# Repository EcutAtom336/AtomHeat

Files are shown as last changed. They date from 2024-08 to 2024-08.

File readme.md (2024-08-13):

# MINI 加热台 - AtomHeat

## 项目简介

- 该项目是基于立创·天空星开发板-GD32F407VET6-青春版的小型加热台。

- 支持使用 Type-C 接口和 5.5*2.5 DC 接口供电。Type-C 接口最高支持 100W PD 协议，DC 接口支持 16.5v-25.5v 电压。

## 快速链接

- [Github](https://github.com/EcutAtom336/AtomHeat)

- [立创开源硬件平台](http://oshwhub.com/dter/atomheat)

## 功能描述

- 使用 Type-C 接口或 DC 接口供电。理论工作电压为 16.5v-25.5v，兼容 5-6 串锂电池实际仅测试 100W PD 供电。

- 内置加速度计和蜂鸣器，当机身倾倒时候会停止加热并发出提示音。

- 5 个触摸按键和一个旋钮编码器，可设置分时分段加热。可储存5个快捷温度预设。

- 1.8 寸 tft lcd，可显示加热功率、当前温度和加热曲线。

## 复刻指南

### 硬件

#### 硬件架构

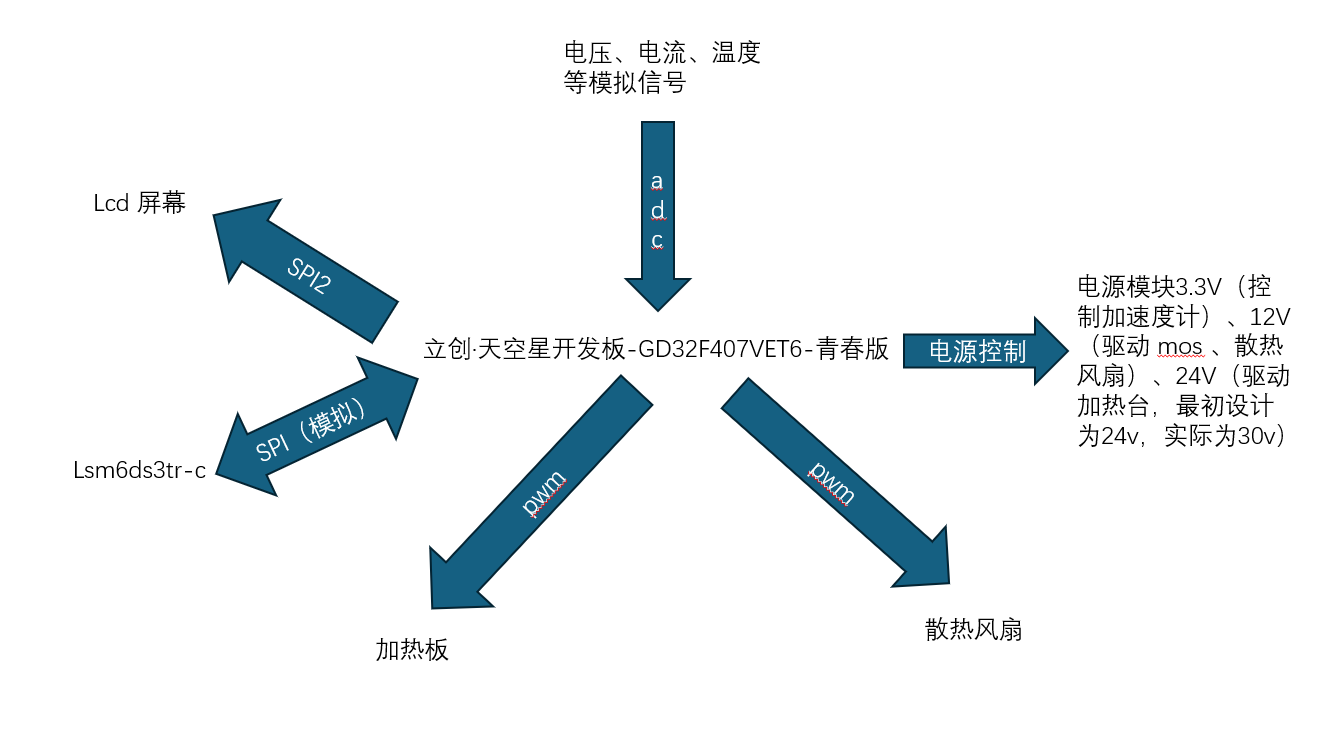
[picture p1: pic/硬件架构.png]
硬件架构


- 项目 BOM 表在 /production_doc 下，分别为：

1. BOM_Board1_V0.3_Schematic1_V0.3_2024-08-13.xlsx

2. BOM_Board2_V0.2_Schematic2_V0.2_2024-08-13.xlsx

- 3D 打印外壳文件在 /production_doc/3d_print 下。

- CNC 制造文件在 /production_doc/cnc 下。

- 面板制造文件在 /production_doc/panel 下。

- PCB 制造文件在 /production_doc/pcb 下。

- 其他硬件在 /production_doc/other.xlsx 有详细介绍和购买地址。

### 软件

#### 软件架构

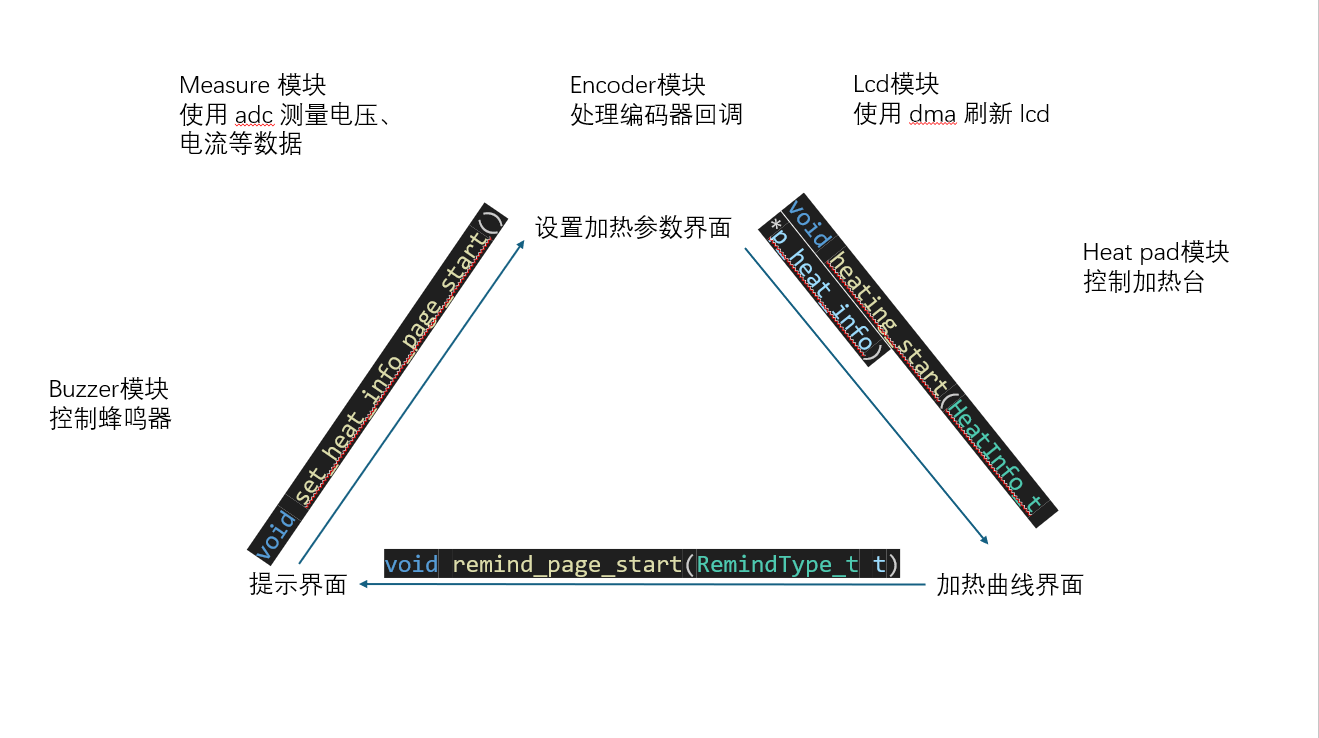
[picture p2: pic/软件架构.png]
软件架构


- 软件使用 EIDE 开发，源码在 /embed 下，该目录 readme 有详细的软件介绍。

### 烧录

- 已编译的固件已上传至附件

- 有多种方式烧录固件，可前往[立创开发板资料](https://lceda001.feishu.cn/wiki/Zawdwg0laig3Qnk2XuxcKrQRn2g)查看详细教程

## 安全警告

- Type-C 接口和 DC 接口没有防倒灌设计，请勿同时使用 Type-C 接口和 DC 接口供电，否则后果自负。

- 加热台工作时，请注意安全。

## 备注

- 加热控制使用 pwm 控制平均功率，瞬时功率大约 120W 以上，即使使用功率限制功能，小功率充电器依然可能过载重启（例如使用 67W 充电器并将最大功率限制在 60W）。

- 当温度达到 300 摄氏度以上时，散热功率接近加热功率，温度上升非常缓慢。

- 为适应项目需求中的低压、高温，本项目使用了 cnc 加工，复刻成本较高。

- 演示视频链接

1.[【星火计划-悬赏赛道】MINI加热台 AtomHeat 功能演示1](https://www.bilibili.com/video/BV15wYYe4EQf/?share_source=copy_web&vd_source=9ee252657cef98d209294340e74664c1)

2.[【星火计划-悬赏赛道】MINI加热台 AtomHeat 功能演示2](https://www.bilibili.com/video/BV1ewYYe4Ey1/?share_source=copy_web&vd_source=9ee252657cef98d209294340e74664c1)

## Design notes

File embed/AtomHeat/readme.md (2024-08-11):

# MINI 加热台 - AtomHeat 软件部分

## 子模块（位于 hal）

- buzzer

对应用提供预设的 buzzer 音频。

向应用层提供以下方法和类型。

```c
typedef enum {
  BuzzerToneSuccess,
  BuzzerToneFail,
  BuzzerToneWarning,
  BuzzerToneClick,
  BuzzerTone4khz500ms,
  BuzzerToneMax
} BuzzerToneNum_t;

/**
 * @brief 蜂鸣器相关初始化
 *
 */
void buzzer_init();

/**
 * @brief 蜂鸣器发声
 *
 * @param tone_num 音频编号
 */
void buzzer_sing(BuzzerToneNum_t tone_num);
```

- encoder

管理编码器相关回调。

向应用层提供以下方法和类型：

```c
typedef void (*EncoderCb_t)(int8_t change_val);

/**
 * @brief 编码器相关初始化
 *
 */
void encoder_init();

/**
 * @brief 添加编码器处理回调（仅支持一个回调）
 *
 * @param cb
 */
void encoder_cb_add(EncoderCb_t cb);

/**
 * @brief 删除编码器处理回调
 *
 */
void encoder_cb_del();
```

- heat_info

加热参数类型和加热参数修正。

向应用层提供以下方法和类型：

```c
typedef struct {
  uint32_t duartion_s;
  uint16_t temp;
} HeatStage_t;

typedef struct {
  uint8_t is_constant : 1;
  uint8_t check_slant : 1;
  uint8_t power_limit;
  HeatStage_t stage[5];
} HeatInfo_t;

/**
 * @brief 检测并修正加热信息参数
 *
 * @param p_heat_info
 */
void heat_info_revise(HeatInfo_t* p_heat_info);
```

- heat_pad

加热板控制相关。

向应用层提供以下方法：

```c
/**
* @brief 加热板相关初始化
*
*/
void heat_pad_init();
/**
 * @brief 失能加热板
 *
 */
void heat_pad_disable();

/**
 * @brief 设置加热台最大功率，该操作会自动使能加热板
 * 
 * @param p 功率
 */
void heat_pad_set_max_pwr(uint8_t p);

/**
 * @brief 设置加热板温度，该操作会自动使能加热板
 * 
 * @param temp 温度
 */
 void heat_pad_set_temp(uint16_t temp);
```

- measure

使用 adc 测量模拟量和管理对应数据。

对应用层提供以下方法和类型：

```c
typedef struct {
  float_t pwr_in_vol;
  float_t heat_pad_temp;
  float_t heat_pad_pwr;
  float_t heat_pad_vol;
  float_t heat_pad_cur;
} MeasurePwrInfo_t;

typedef struct {
  float_t acc_x_mg, acc_y_mg, acc_z_mg, acc_mg_all;
  float_t deg_x_mg, deg_y_mg, deg_z_mg, deg_mg_all;
} MeasureSportInfo_t;

void measure_init();

/**
 * @brief 获取功率数据
 *
 * @param out 输出指针
 */
void measure_pwr_data_get(MeasurePwrInfo_t *out);

/**
 * @brief 获取运动数据
 *
 * @param out 输出指针
 */
void measure_sport_data_get(MeasureSportInfo_t *out);
```

- pid

pid 算法相关。

对应用层提供以下方法和类型：

```c
typedef struct {
  float_t kp, ki, kd;
  float_t integral, integral_max;
  float_t current, target;
  float_t last_err;
  float_t out, out_min, out_max;
} PidDirData_t;

typedef struct {
  float_t kp, ki, kd;
  float_t last_err1, last_err2;
  float_t target, current, dead_space;
  float_t inc_val;
} PidIncData_t;

/**
 * @brief 位置式 pid 运算
 *
 * @param pid_data pid 数据
 */
void pid_dir(PidDirData_t *pid_data);

/**
 * @brief 增量式 pid 运算
 *
 * @param pin_data pid 数据
 */
void pid_inc(PidIncData_t *pin_data);
```

- pwr_manage

电源管理相关。

对应用层提供以下方法：

```c
/**
 * @brief 使能 3.3v_3 电源（用于控制加速度计）
 * 
 */
void pwr_manage_3v3_3_enable();

/**
 * @brief 失能 3.3v_3 电源（用于控制加速度计）
 * 
 */
void pwr_manage_3v3_3_disable();

/**
 * @brief 使能 12v 电源
 * 
 */
void pwr_manage_12v_enable();

/**
 * @brief 失能 12v 电源
 * 
 */
void pwr_manage_12v_disable();

/**
 * @brief 使能 24v 电源（设计之初电压为24中，实际电源不是24v）
 * 
 */
void pwr_manage_24v_enable();

/**
 * @brief 失能 24v 电源（设计之初电压为24中，实际电源不是24v）
 * 
 */
void pwr_manage_24v_disable();

/**
 * @brief 设置系统散热风扇 pwm 占空比
 * 
 * @param duty 
 */
void pwr_manage_sys_fan_duty_set(uint8_t duty);

/**
 * @brief 设置加热板散热风扇 pwm 占空比
 * 
 * @param duty 
 */
void pwr_manage_heat_pad_fan_duty_set(uint8_t duty);
```

## 应用模块（位于 app）

- set_heat_info_page

用于设置加热参数，启动加热流程。

提供以下方法：

```c
/**
 * @brief 初始化设置加热参数界面
 * 
 */
void set_heat_info_page_init();

/**
 * @brief 启动设置加热参数界面
 * 
 */
void set_heat_info_page_start();

/**
 * @brief 停止设置加热参数界面
 * 
 */
void set_heat_info_page_stop();
```

- heating_page

显示功率、温度和温度曲线，倾倒检测。

提供以下方法：

```c
/**
 * @brief 加热时任务初始化
 * 
 */
void heating_init();

/**
 * @brief 启动加热
 * 
 * @param p_heat_info 
 */
void heating_start(HeatInfo_t *p_heat_info);

/**
 * @brief 停止加热
 * 
 */
void heating_stop();
```

- remind_page

提示界面。由 heating 界面启动，用于提示用户。

提供以下类型和方法：

```c
typedef enum {
  RemindTypeNone,
  RemindTypeVl,
  RemindTypeSlant,
  RemindTypeFinish,
  RemindTypeMax
} RemindType_t;

/**
 * @brief 提示页相关初始化
 *
 */
void remind_page_init();

/**
 * @brief 启动提示页
 *
 * @param remind 提示信息
 */
void remind_page_start(RemindType_t remind);

/**
 * @brief 停止提示页
 *
 */
void remind_page_stop();
```

## 其他软件

- 响应式按键管理库 [Multi_button](https://github.com/0x1abin/MultiButton)

- 轻量级 flash 管理库 [EasyFlash](https://github.com/armink/EasyFlash.git)

- 轻量级 log 库 [EasyLogger](https://github.com/armink/EasyLogger.git)

- st lsm6ds3tr-c 驱动库 [lsm6ds3tr-c-pid](https://github.com/STMicroelectronics/lsm6ds3tr-c-pid.git)

- 轻量级 rtos [Freertos](https://github.com/FreeRTOS/FreeRTOS.git)

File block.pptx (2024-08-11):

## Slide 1

Measure 模块
使用 adc 测量电压、电流等数据

Encoder模块
处理编码器回调

Lcd模块
使用 dma 刷新 lcd

void set_heat_info_page_start()

设置加热参数界面

Heat pad模块
控制加热台

void heating_start(HeatInfo_t *p_heat_info)

Buzzer模块
控制蜂鸣器

void remind_page_start(RemindType_t t)

提示界面

加热曲线界面

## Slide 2

电压、电流、温度等模拟信号

Lcd 屏幕

adc

SPI2

电源模块3.3V（控制加速度计）、12V（驱动 mos 、散热风扇）、24V（驱动加热台，最初设计为24v，实际为30v）

立创·天空星开发板-GD32F407VET6-青春版

电源控制

SPI（模拟）

Lsm6ds3tr-c

pwm

pwm

散热风扇

加热板

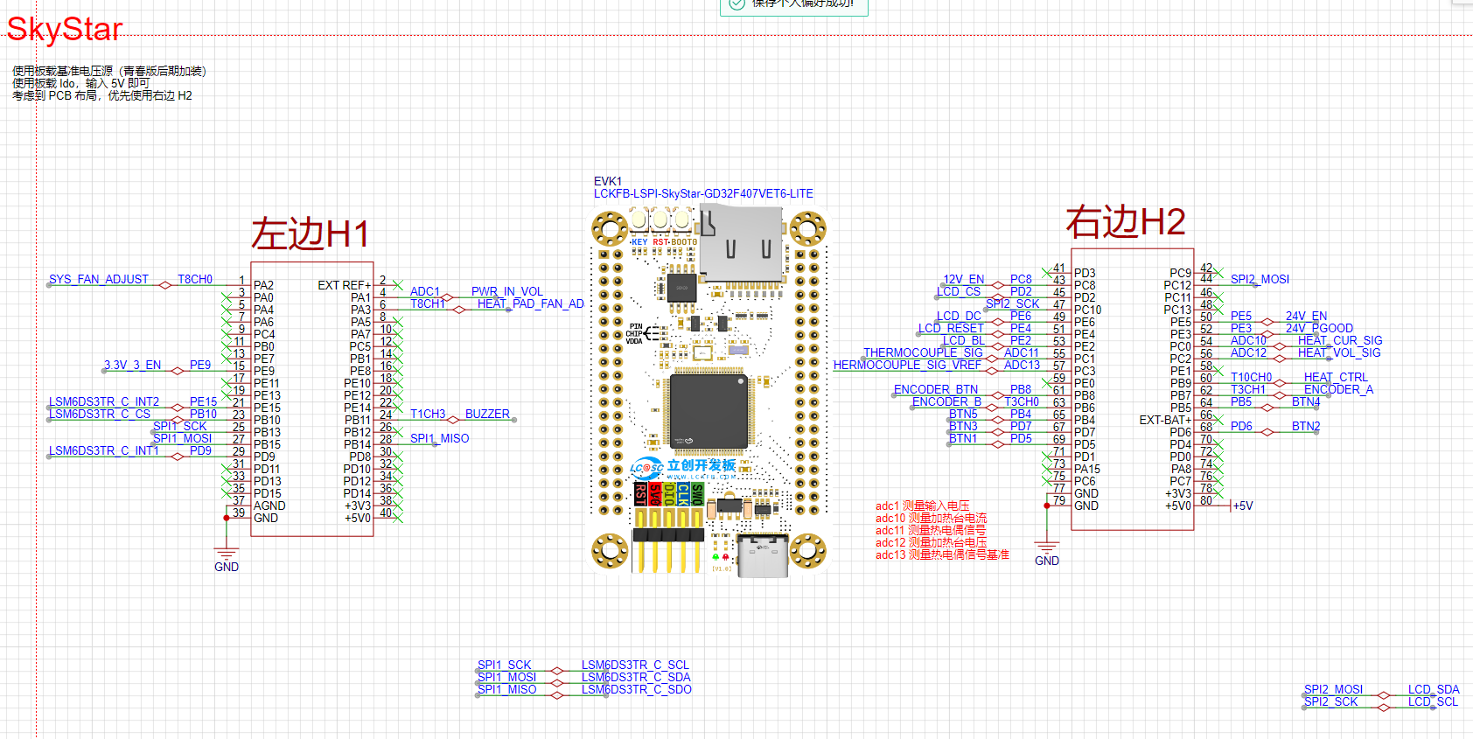
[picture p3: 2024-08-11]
pic/主控.png

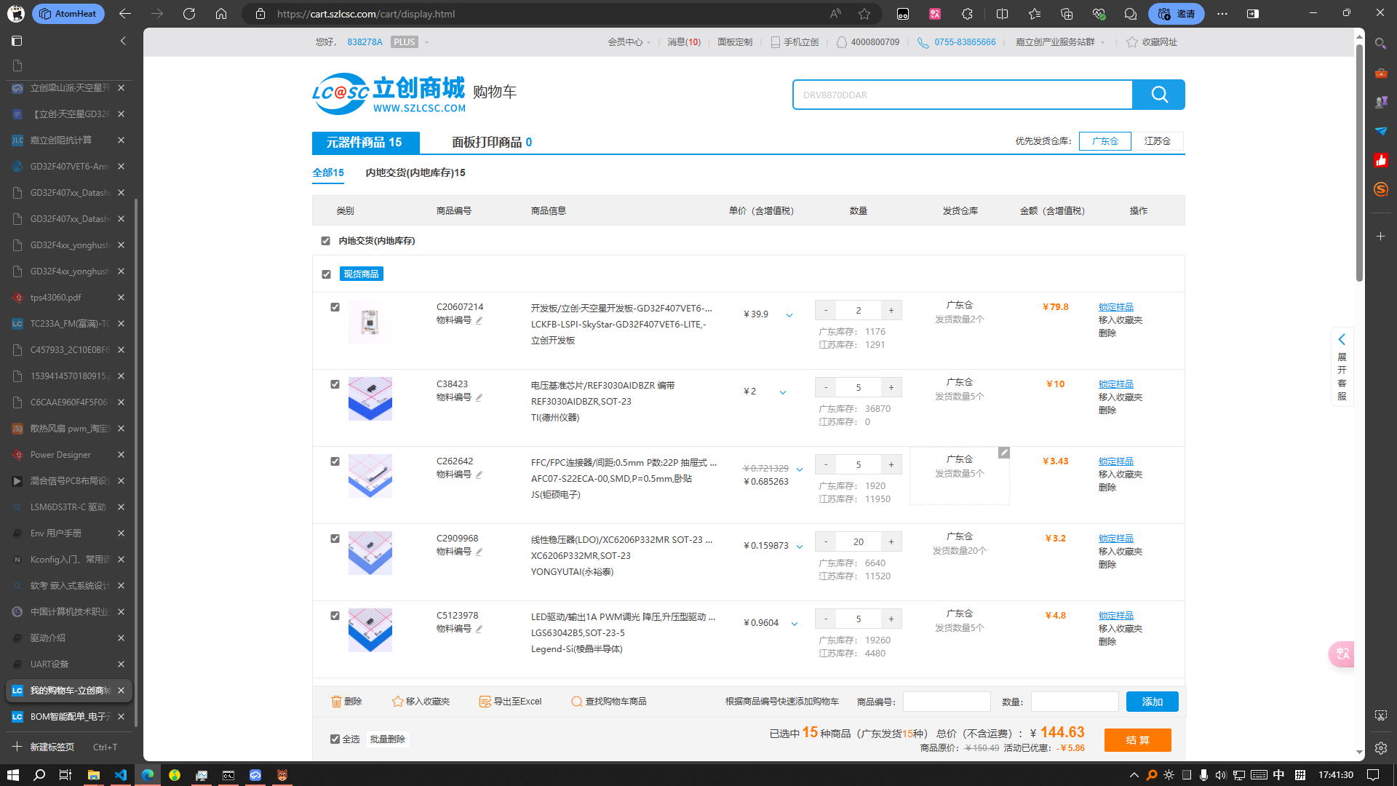
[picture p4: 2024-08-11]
pic/耗材申请图片/屏幕截图(46).png

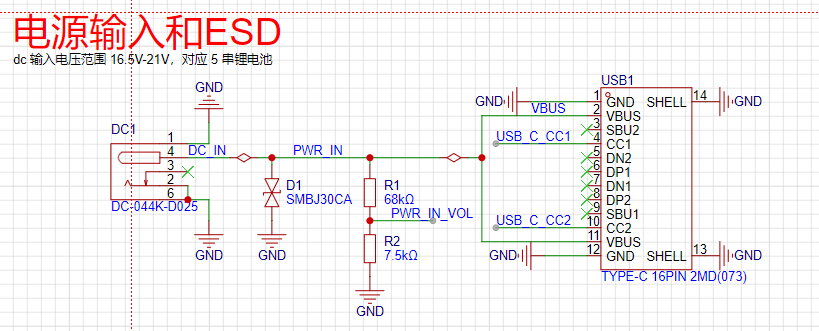
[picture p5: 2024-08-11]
pic/电源输入和ESD.png

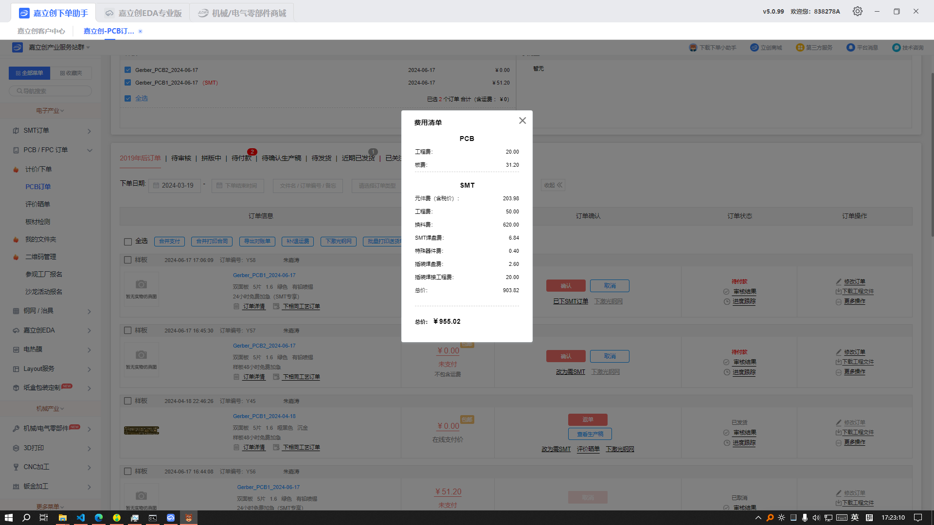
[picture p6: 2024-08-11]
pic/耗材申请图片/屏幕截图(45).png

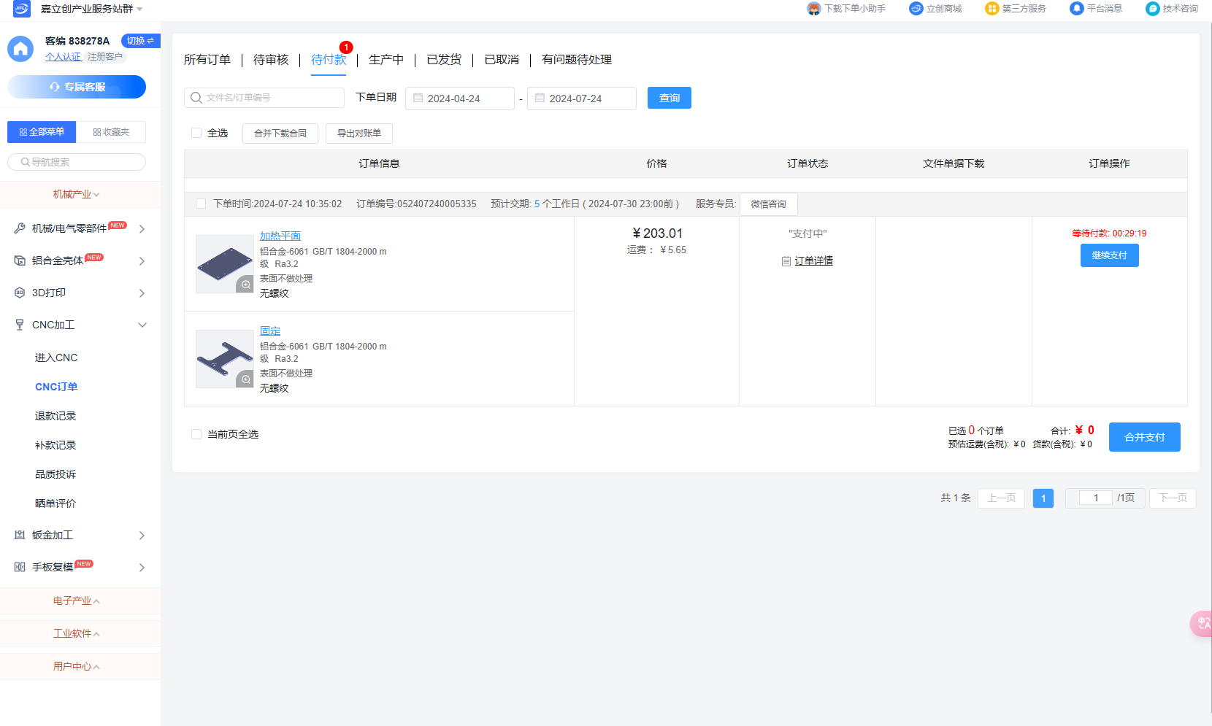
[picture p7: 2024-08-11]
pic/耗材申请图片/屏幕截图(54).png

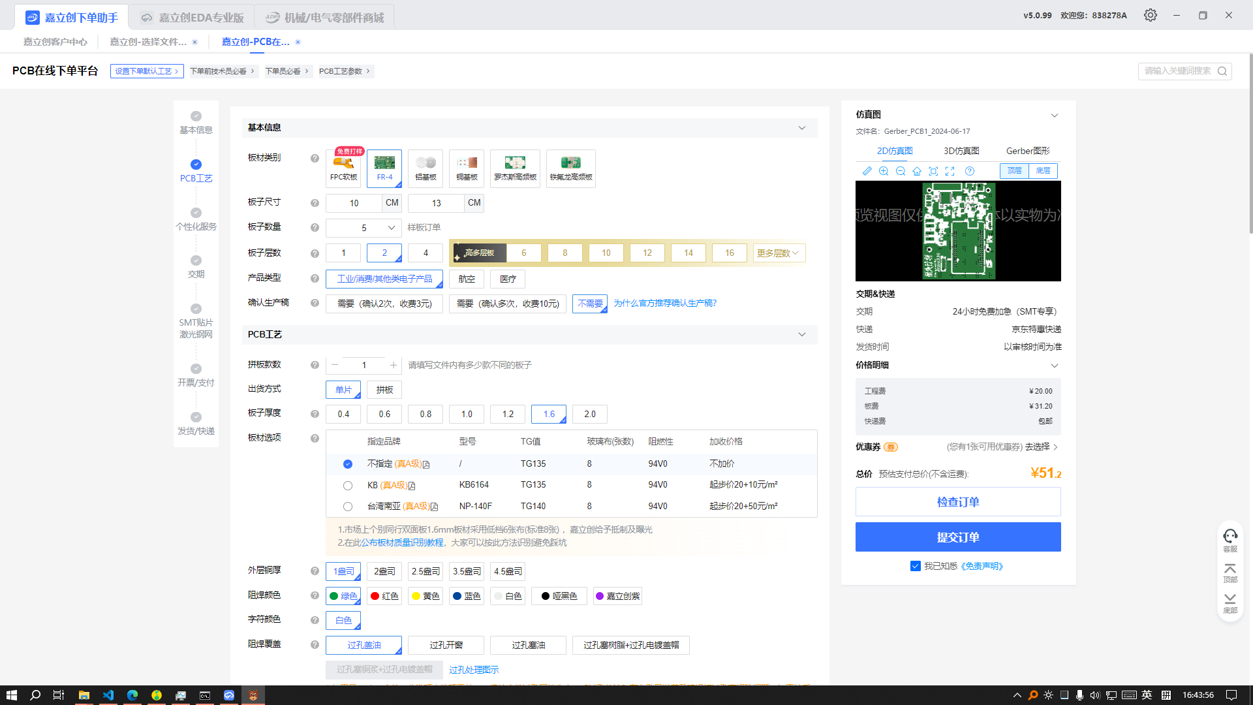
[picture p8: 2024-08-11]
pic/耗材申请图片/屏幕截图(42).png

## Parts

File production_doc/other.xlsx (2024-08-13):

购买链接只是参考，自己对规格，找便宜的
 | 数量 | 购买链接 | 备注
4cm 散热风扇 | 1 | 电脑风扇456CM 789/12厘米4010 5010 6025 4线PWM温控CPU散热风扇-淘宝网 (taobao.com) (https://item.taobao.com/item.htm?id=708877662849&_u=9207b9sukh01e2) | 替换注意线序和接口
5cm 散热风扇 | 1 | 电脑风扇456CM 789/12厘米4010 5010 6025 4线PWM温控CPU散热风扇-淘宝网 (taobao.com) (https://item.taobao.com/item.htm?id=708877662849&_u=9207b9sukh01e2) | 替换注意线序和接口
M2*16 | 4 | 沉头厚0.8mm，找便宜的 | 用于固定操作面板
M2*6 | 4 | 沉头厚0.8mm，找便宜的 | 用于固定加热片
M2螺母 | 8 | 国标件，找便宜的
M3*8 | 12 | 沉头厚1mm，找便宜的
M3*16 | 12 | 沉头厚1mm，找便宜的
M3螺母 | 8 | 国标件，找便宜的
M3*30不锈钢螺柱 | 4 | 不锈钢、铜都行，接触高温建议不锈钢，不然会氧化 | 用于连接加热板和隔热板
M3*45铜螺柱 | 4 | 不锈钢、铜都行，放在里面看不到，铜的便宜 | 用于连接控制主板和隔热板
15*70mm加热片 10R | 2 | RP1570 1/2/5/10/20/230Ω高温陶瓷 MCH加热片可干烧1000度电热片-淘宝网 (taobao.com) (https://item.taobao.com/item.htm?id=634543980327&_u=b207b9sukhb010)

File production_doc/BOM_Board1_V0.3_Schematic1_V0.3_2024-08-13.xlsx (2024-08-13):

No. | Quantity | Comment | Designator | Footprint | Value | Manufacturer Part | Manufacturer | Supplier Part | Supplier
1 | 1 | 4kHz | BUZZER1 | BUZ-SMD_L5.0-W5.5-P4.60 | 4kHz | MLT-5020 | 华能 | C94598 | LCSC
2 | 9 | 1uF | C1,C2,C3,C4,C5,C10,C21,C40,C58 | C0603 | 1uF | CL10A105KB8NNNC | SAMSUNG(三星) | C15849 | LCSC
3 | 1 | 220nF | C6 | C0603 | 220nF | CL10B224KB8NNNC | SAMSUNG(三星) | C64705 | LCSC
4 | 2 | 10uF | C7,C8 | C0603 | 10uF | CL10A106KP8NNNC | SAMSUNG(三星) | C19702 | LCSC
5 | 13 | 100nF | C9,C11,C12,C17,C19,C20,C38,C39,C41,C50,C51,C52,C57 | C0603 | 100nF | CC0603KRX7R9BB104 | YAGEO(国巨) | C14663 | LCSC
6 | 1 | 10uF | C13 | C0603 | 10uF | CL10A106MA8NRNC | SAMSUNG(三星) | C96446 | LCSC
7 | 1 | 4.7nF | C14 | C0603 | 4.7nF | GRM1885C1H472JA01D | muRata(村田) | C85980 | LCSC
8 | 1 | 300pF | C15 | C0603 | 300pF | CC0603KRX7R9BB301 | YAGEO(国巨) | C282248 | LCSC
9 | 1 | 6.8nF | C16 | C0603 | 6.8nF | 0603B682K500NT | FH(风华) | C1631 | LCSC
10 | 1 | 100pF | C18 | C0603 | 100pF | CL10C101JB8NNNC | SAMSUNG(三星) | C14858 | LCSC
11 | 15 | 100uF | C22,C23,C24,C25,C26,C27,C28,C30,C31,C32,C33,C34,C35,C36,C37 | CAP-TH_BD8.0-P3.50-D0.6-FD | 100uF | SPZ1HM101F09O00RAXXX | AISHI(艾华集团) | C171434 | LCSC
12 | 10 | 22uF | C42,C43,C44,C45,C46,C47,C48,C49,C55,C56 | C0805 | 22uF | CGA0805X5R226M350MT | HRE(芯声) | C6119901 | LCSC
13 | 1 | 56pF | C53 | C0603 | 56pF | CC0603FRNPO9BN560 | YAGEO(国巨) | C527049 | LCSC
14 | 1 | 68pF | C54 | C0603 | 68pF | 0603CG680J500NT | FH(风华) | C1680 | LCSC
15 | 2 | 2510-4A | CN1,CN2 | CONN-TH_4P-P2.54_CAX_2510-4A |  | 2510-4A | CAX(创都) | C2847671 | LCSC
16 | 1 | SMBJ30CA | D1 | SMB_L4.3-W3.6-LS5.4-BI |  | SMBJ30CA | Liown(里阳半导体) | C2925441 | LCSC
17 | 2 | 1N5819WS | D2,D4 | SOD-323_L1.8-W1.3-LS2.5-RD |  | 1N5819WS | Hottech(合科泰) | C191023 | LCSC
18 | 1 | SS14 | D3 | SMA_L4.3-W2.6-LS5.0-RD |  | SS14 | JSMSEMI(杰盛微) | C2837270 | LCSC
19 | 1 | DC-044K-D025 | DC1 | DC-IN-TH_DC-044K-D025 |  | DC-044K-D025 | G-Switch(品赞) | C963204 | LCSC
20 | 1 | LCKFB-LSPI-SkyStar-GD32F407VET6-LITE | EVK1 | DIP-80_L44.97-W69.97-P2.54X2-LS35.9 |  | LCKFB-LSPI-SkyStar-GD32F407VET6-LITE | 立创开发板 | C20607214 | LCSC
21 | 1 | AFC01-S16FCA-00 | FPC1 | FPC-SMD_P0.50-16P_FGS-XJ-H2.0 |  | AFC01-S16FCA-00 | JS(钜硕电子) | C262665 | LCSC
22 | 1 | 6.8uH | L1 | IND-SMD_L17.2-W17.2_FAUL1770 | 6.8uH | FAUL1770-6R8MT | cjiang(长江微电) | C5298362 | LCSC
23 | 2 | 10uH | L2,L3 | IND-SMD_L7.3-W6.8 | 10uH | FXL0630-100-M | cjiang(长江微电) | C167223 | LCSC
24 | 2 | SS8050 | Q1,Q4 | SOT-23-3_L2.9-W1.3-P1.90-LS2.4-BR |  | SS8050 | CJ(江苏长电/长晶) | C2150 | LCSC
25 | 1 | NCE4009S | Q2 | SOIC-8_L5.0-W4.0-P1.27-LS6.0-BL |  | NCE4009S | NCE(无锡新洁能) | C189610 | LCSC
26 | 1 | SS8550 Y2 | Q3 | SOT-23-3_L2.9-W1.3-P1.90-LS2.4-BR |  | SS8550 Y2 | CJ(江苏长电/长晶) | C8542 | LCSC
27 | 2 | CSD18543Q3A | Q5,Q6 | VSONP-8_L3.1-W3.1-P0.65-LS3.5-BL |  | CSD18543Q3A | TI(德州仪器) | C840100 | LCSC
28 | 2 | 68kΩ | R1,R19 | R0603 | 68kΩ | 0603WAF6802T5E | UNI-ROYAL(厚声) | C23231 | LCSC
29 | 2 | 7.5kΩ | R2,R23 | R0603 | 7.5kΩ | 0603WAF7501T5E | UNI-ROYAL(厚声) | C23234 | LCSC
30 | 1 | 1kΩ | R3 | R0603 | 1kΩ | 0603WAF1001T5E | UNI-ROYAL(厚声) | C21190 | LCSC
31 | 9 | 10kΩ | R4,R5,R8,R9,R17,R18,R21,R32,R36 | R0603 | 10kΩ | 0603WAF1002T5E | UNI-ROYAL(厚声) | C25804 | LCSC
32 | 3 | 100kΩ | R6,R30,R31 | R0603 | 100kΩ | 0603WAF1003T5E | UNI-ROYAL(厚声) | C25803 | LCSC
33 | 3 | 0Ω | R7,R12,R22 | R0603 | 0Ω | 0603WAF0000T5E | UNI-ROYAL(厚声) | C21189 | LCSC
34 | 1 | 2Ω | R10 | R0603 | 2Ω | 0603WAF200KT5E | UNI-ROYAL(厚声) | C22977 | LCSC
35 | 1 | 5.1kΩ | R11 | R0603 | 5.1kΩ | 0603WAF5101T5E | UNI-ROYAL(厚声) | C23186 | LCSC
36 | 1 | 105kΩ | R13 | R0603 | 105kΩ | 0603WAF1053T5E | UNI-ROYAL(厚声) | C16840 | LCSC
37 | 1 | 5mΩ | R14 | R1206 | 5mΩ | HoLLR1206-1W-5mR-1% | Milliohm(毫欧) | C2988648 | LCSC
38 | 1 | 261kΩ | R15 | R0603 | 261kΩ | ERJ3EKF2613V | PANASONIC(松下) | C403113 | LCSC
39 | 1 | 11kΩ | R16 | R0603 | 11kΩ | 0603WAF1102T5E | UNI-ROYAL(厚声) | C25950 | LCSC
40 | 1 | 100Ω | R20 | R0603 | 100Ω | 0603WAF1000T5E | UNI-ROYAL(厚声) | C22775 | LCSC
41 | 2 | 10Ω | R24,R25 | R0603 | 10Ω | 0603WAF100JT5E | UNI-ROYAL(厚声) | C22859 | LCSC
42 | 2 | 8mΩ | R26,R27 | R1206 | 8mΩ | HoLLR1206-1W-8mR-1% | Milliohm(毫欧) | C2988654 | LCSC
43 | 1 | 1MΩ | R29 | R0603 | 1MΩ | 0603WAF1004T5E | UNI-ROYAL(厚声) | C22935 | LCSC
44 | 1 | 5.23kΩ | R33 | R0603 | 5.23kΩ | 0603WAF5231T5E | UNI-ROYAL(厚声) | C23068 | LCSC
45 | 1 | 13.7kΩ | R34 | R0603 | 13.7kΩ | 0603WAF1372T5E | UNI-ROYAL(厚声) | C22793 | LCSC
46 | 1 | 20kΩ | R35 | R0603 | 20kΩ | 0603WAF2002T5E | UNI-ROYAL(厚声) | C4184 | LCSC
47 | 2 | XC6206P332MR | U1,U3 | SOT-23-3_L2.9-W1.3-P0.95-LS2.4-BR |  | XC6206P332MR | YONGYUTAI(永裕泰) | C2909968 | LCSC
48 | 1 | CH224K | U2 | ESSOP-10_L4.9-W3.9-P1.0-LS6.0-TL-EP |  | CH224K | WCH(南京沁恒) | C970725 | LCSC
49 | 1 | TPS43060RTER | U4 | WQFN-16_L3.0-W3.0-P0.50-TL-EP |  | TPS43060RTER | TI(德州仪器) | C76516 | LCSC
50 | 1 | INA180A3IDBVR | U5 | SOT-23-5_L3.0-W1.7-P0.95-LS2.8-BR |  | INA180A3IDBVR | TI(德州仪器) | C122882 | LCSC
51 | 1 | LP5907MFX-3.3/NOPB | U6 | SOT-23-5_L3.0-W1.7-P0.95-LS2.8-BR |  | LP5907MFX-3.3/NOPB | TI(德州仪器) | C80670 | LCSC
52 | 2 | MX25C-7.62-02P-BK01-Cu-S-A | U7,U9 | CONN-TH_2P-P7.62_MAX_MX25C-7.62-BK01-02P-CU-S-A |  | MX25C-7.62-02P-BK01-Cu-S-A | MAX(迈旭) | C5188509 | LCSC
53 | 1 | LSM6DS3TR-C | U8 | LGA-14_L3.0-W2.5-P0.50-TL |  | LSM6DS3TR-C | ST(意法半导体) | C967633 | LCSC
54 | 1 | AD8495ARMZ | U10 | MSOP-8_L3.0-W3.0-P0.65-LS4.9-BL |  | AD8495ARMZ | ADI(亚德诺) | C578736 | LCSC
55 | 2 | TPS54202DDCR | U11,U12 | SOT-23-6_L2.9-W1.6-P0.95-LS2.8-BL |  | TPS54202DDCR | TI(德州仪器) | C191884 | LCSC
56 | 1 | GN358DR | U13 | SOP-8_L4.9-W3.9-P1.27-LS6.0-BL |  | GN358DR | GN(旌芯半导体) | C332097 | LCSC
57 | 1 | TYPE-C 16PIN 2MD(073) | USB1 | USB-C-SMD_TYPE-C-6PIN-2MD-073 |  | TYPE-C 16PIN 2MD(073) | SHOU HAN(首韩) | C2765186 | LCSC

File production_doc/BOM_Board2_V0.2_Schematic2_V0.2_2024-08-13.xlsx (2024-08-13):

No. | Quantity | Comment | Designator | Footprint | Value | Manufacturer Part | Manufacturer | Supplier Part | Supplier
1 | 8 | 100nF | C1,C5,C7,C8,C9,C11,C13,C15 | C0603 | 100nF | CC0603KRX7R9BB104 | YAGEO(国巨) | C14663 | LCSC
2 | 3 | 1uF | C3,C4,C10 | C0603 | 1uF | CL10A105KB8NNNC | SAMSUNG(三星) | C15849 | LCSC
3 | 1 | AFC01-S16FCA-00 | FPC1 | FPC-SMD_P0.50-16P_FGS-XJ-H2.0 |  | AFC01-S16FCA-00 | JS(钜硕电子) | C262665 | LCSC
4 | 1 | SS8050 | Q4 | SOT-23-3_L2.9-W1.3-P1.90-LS2.4-BR |  | SS8050 | CJ(江苏长电/长晶) | C2150 | LCSC
5 | 5 | TC233A | R1,R3,R5,R7,R10 | SOT-23-6_L2.9-W1.6-P0.95-LS2.8-BL |  | TC233A | FM(富满) | C2798022 | LCSC
6 | 5 | 0Ω | R2,R4,R6,R9,R11 | R0603 | 0Ω | 0603WAF0000T5E | UNI-ROYAL(厚声) | C21189 | LCSC
7 | 1 | 10Ω | R8 | R0805_NEW | 10Ω | 0805W8F100JT5E | UNI-ROYAL(厚声) | C17415 | LCSC
8 | 1 | 10kΩ | R12 | R0603 | 10kΩ | 0603WAF1002T5E | UNI-ROYAL(厚声) | C25804 | LCSC
9 | 1 | EC11L1525G01 | SW1 | SW-TH_ALPS_EC11L1525G01 |  | EC11L1525G01 | ALPSALPINE(阿尔卑斯阿尔派) | C2991196 | LCSC
10 | 1 | XC6206P332MR | U1 | SOT-23-3_L2.9-W1.3-P0.95-LS2.4-BR |  | XC6206P332MR | YONGYUTAI(永裕泰) | C2909968 | LCSC

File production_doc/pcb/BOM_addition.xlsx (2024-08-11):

No. | Quantity | Comment | Designator | Footprint | Value | Manufacturer Part | Manufacturer | Supplier Part | Supplier
1 | 1 | 10uF | C1 | C0603 | 10uF | CL10A106MA8NRNC | SAMSUNG(三星) | C96446 | LCSC | 另一块板子使用了免费券
2 | 8 | 100nF | C2,C3,C7,C8,C9,C11,C13,C15 | C0603 | 100nF | CC0603KRX7R9BB104 | YAGEO(国巨) | C14663 | LCSC | 另一块板子使用了免费券
3 | 2 | 1uF | C5,C6 | C0603 | 1uF | CL10A105KB8NNNC | SAMSUNG(三星) | C15849 | LCSC | 另一块板子使用了免费券
4 | 1 | SS14 | D1 | SMA_L4.3-W2.6-LS5.0-RD |  | SS14 | JSMSEMI(杰盛微) | C2837270 | LCSC | 另一块板子使用了免费券
5 | 1 | AFC01-S28FCC-00 | FPC2 | FPC-SMD_P0.50-28P_FGS-XJ-H2.0 |  | AFC01-S28FCC-00 | JS(钜硕电子) | C262278 | LCSC | 另一块板子使用了免费券
6 | 1 | 10uH | L1 | IND-SMD_L4.4-W4.2 | 10uH | SLO0420H100MTT | Sunltech(韩国顺磁) | C207832 | LCSC | 另一块板子使用了免费券
7 | 1 | 2.49Ω | R1 | R0603 | 2.49Ω | 0603WAF249KT5E | UNI-ROYAL(厚声) | C247053 | LCSC | 另一块板子使用了免费券
8 | 5 | TC233A | R8,R10,R12,R14,R16 | SOT-23-6_L2.9-W1.6-P0.95-LS2.8-BL |  | TC233A | FM(富满) | C2798022 | LCSC | 另一块板子使用了免费券
9 | 5 | 0Ω | R9,R11,R13,R15,R17 | R0603 | 0Ω | 0603WAF0000T5E | UNI-ROYAL(厚声) | C21189 | LCSC | 另一块板子使用了免费券
10 | 1 | E6E8-2.7C5-12B15 | SW1 | SW-SMD_L5.7-W5.7-P2.00-LS6.9 |  | E6E8-2.7C5-12B15 | G-Switch(品赞) | C976312 | LCSC | 另一块板子使用了免费券
11 | 1 | LGS63042B5 | U1 | SOT-23-5_L2.9-W1.6-P0.95-LS2.8-BL |  | LGS63042B5 | Legend-Si(棱晶半导体) | C5123978 | LCSC | 另一块板子使用了免费券
12 | 1 | XC6206P332MR | U2 | SOT-23-3_L2.9-W1.3-P0.95-LS2.4-BR |  | XC6206P332MR | YONGYUTAI(永裕泰) | C2909968 | LCSC | 另一块板子使用了免费券
13 | 1 | AFC07-S22ECA-00 | X1 | FPC-SMD_AFC07-S22ECA-00 |  | AFC07-S22ECA-00 | JS(钜硕电子) | C262642 | LCSC | 另一块板子使用了免费券
14 | 1 | REF3030AIDBZR |  |  |  |  |  | C38423 | LCSC | 贴在开发板上
15 | 1 | 立创·天空星开发板-GD32F407VET6-青春版 |  |  |  |  |  | C20607214 | LCSC | smt已删除

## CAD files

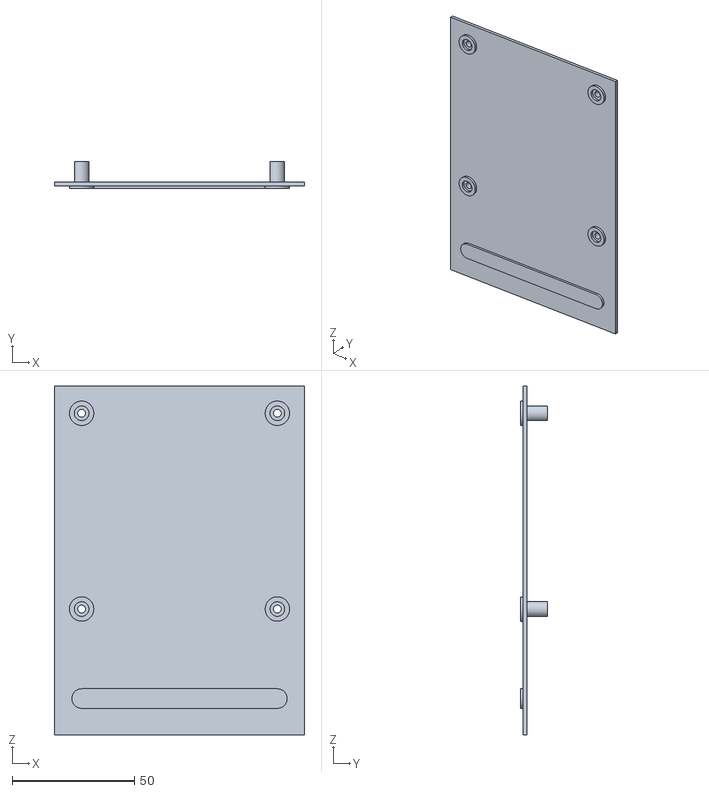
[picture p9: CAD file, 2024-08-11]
production_doc/3d_print/底板.STL
102.3 x 11.2 x 142.6

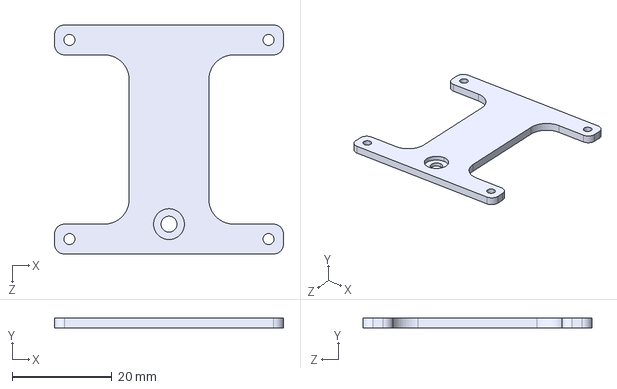
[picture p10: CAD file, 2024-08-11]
production_doc/cnc/固定.STEP
46.0 x 2.00 x 46.0 mm

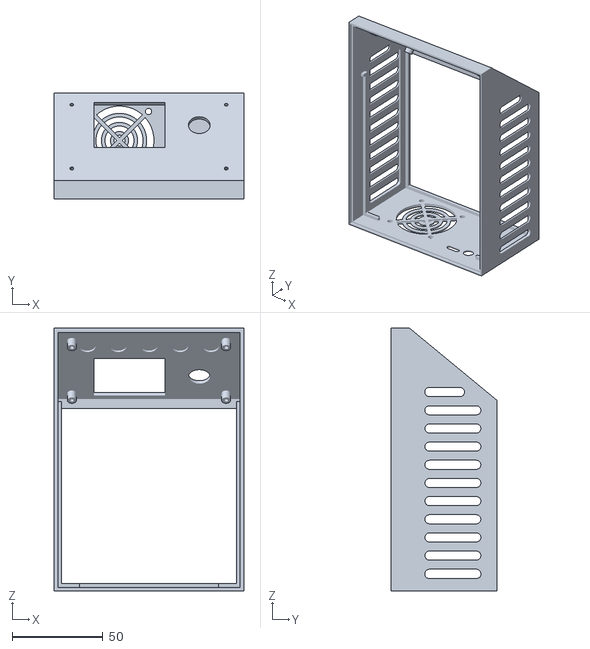
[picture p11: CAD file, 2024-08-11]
production_doc/3d_print/外壳.STL
104.5 x 58.2 x 144.8

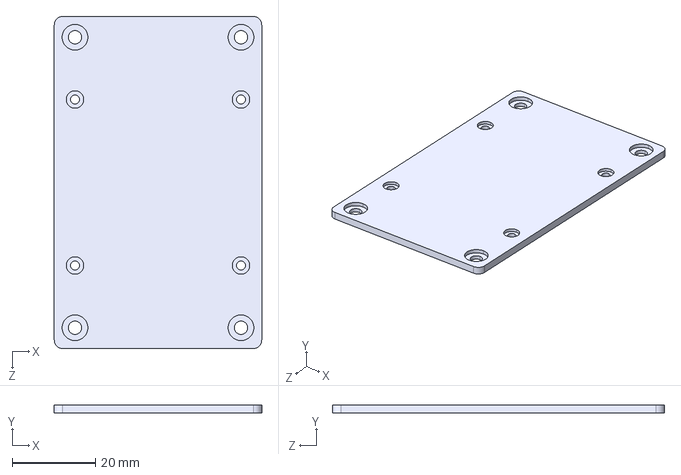
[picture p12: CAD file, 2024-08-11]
production_doc/cnc/加热平面.STEP
50.0 x 2.00 x 80.0 mm

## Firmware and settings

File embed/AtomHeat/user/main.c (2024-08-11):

#include "buzzer.h"
#include "hw_init.h"
#include "lcd_init.h"
#include "pwr_manage.h"
#include "remind_page.h"
#include "heat_pad.h"
#include "led.h"
#include "my_lcd.h"
#include "encoder.h"
#include "measure.h"
#include "heating.h"
#include "multi_button_port.h"
#include "my_lcd.h"
#include "set_heat_info_page.h"
#include "logo_page.h"
/***/
#define LOG_TAG "main"
#include "elog.h"
//
#include "easyflash.h"
//
#include "FreeRTOS.h"
#include "task.h"
/***/
#include "systick.h"
#include "gd32f4xx.h"
/***/
#include <stddef.h>
#include <stdio.h>

static TaskHandle_t init_task_handle;
static StaticTask_t init_task;
static uint8_t init_task_stack[2048];

static void init_code() {
  elog_init();
  elog_set_fmt(ELOG_LVL_ASSERT, ELOG_FMT_ALL);
  elog_set_fmt(ELOG_LVL_ERROR, ELOG_FMT_LVL | ELOG_FMT_TAG | ELOG_FMT_TIME);
  elog_set_fmt(ELOG_LVL_WARN, ELOG_FMT_LVL | ELOG_FMT_TAG | ELOG_FMT_TIME);
  elog_set_fmt(ELOG_LVL_INFO, ELOG_FMT_LVL | ELOG_FMT_TAG | ELOG_FMT_TIME);
  elog_set_fmt(ELOG_LVL_DEBUG, ELOG_FMT_LVL | ELOG_FMT_TAG | ELOG_FMT_TIME);
  elog_set_fmt(ELOG_LVL_VERBOSE, ELOG_FMT_LVL | ELOG_FMT_TAG | ELOG_FMT_TIME);
  elog_start();

  on_chip_hw_init();   // 片上硬件初始化
  on_board_hw_init();  // 板级硬件初始化

  // fmc_wscnt_set(WS_WSCNT_15);

  // 软件包初始化
  EfErrCode ef_err;
  ef_err = easyflash_init();
  configASSERT(ef_err == EF_NO_ERR);

  // lcd 初始化
  LCD_Init();
  lcd_handler_init();

  // 所有任务使用静态分配方式，在此初始化

  led_init();                // 开发板 led 初始化
  multi_button_port_init();  // 按键扫描任务
  buzzer_init();             // 蜂鸣器任务
  measure_init();            // 测量任务
  encoder_init();            // 编码器任务
  heat_pad_init();           // 加热台

  // 应用程序任务初始化
  logo_page_init();
  set_heat_info_page_init();
  heating_init();
  remind_page_init();

  pwr_manage_12v_enable();
  pwr_manage_24v_enable();

  // 开机提示音
  buzzer_sing(BuzzerToneSuccess);

  // 启动 LOGO 页
  logo_page_start();

  lcd_refreash_request();

  // 显示开机次数
  uint32_t boot_count, saved_size, read_size;
  read_size = ef_get_env_blob("bootCount", &boot_count, sizeof(boot_count),
                              &saved_size);
  log_d("read size: %u, saved size: %u, boot count: %u", read_size, saved_size,
        boot_count);

  boot_count++;
  ef_err = ef_set_env_blob("bootCount", &boot_count, sizeof(uint32_t));
  log_d("ef err: %u", ef_err);

  vTaskDelete(NULL);
}

int main() {
  nvic_priority_group_set(NVIC_PRIGROUP_PRE4_SUB0);

  init_task_handle = xTaskCreateStatic(
      init_code, "init", sizeof(init_task_stack) / 4, NULL,
      configMAX_PRIORITIES - 1, (StackType_t *)init_task_stack, &init_task);
  configASSERT(init_task_handle);

  systick_config();

  vTaskStartScheduler();
}

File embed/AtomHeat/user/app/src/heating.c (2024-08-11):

#include "heating.h"
/***/
#include "heat_info.h"
#include "buzzer.h"
#include "set_heat_info_page.h"
#include "remind_page.h"
#include "my_lcd.h"
#include "color.h"
#include "heat_pad.h"
#include "measure.h"
#include "multi_button_port.h"
#include "lcd_init.h"
/***/
#define LOG_TAG "heating"
#include "elog.h"
//
#include "multi_button.h"
//
#include "FreeRTOS.h"
#include "semphr.h"
#include "event_groups.h"
#include "task.h"
/***/
#include <stdio.h>
#include <stdlib.h>
#include <stdint.h>
#include <string.h>

static TaskHandle_t heating_task_handle;
static StaticTask_t heating_task;
static uint8_t heating_task_stack[1024];

static struct Button encoder_btn;

static uint16_t temp_record[140];
static uint32_t record_num;
static uint16_t temp_show_x[140];
static uint16_t temp_show_y[140];
static uint16_t cur_power, cur_temp;

static HeatInfo_t heat_info;

static uint16_t find_max;

static void heating_ui_renew_cn() {
  lcd_fill(0, 0, LCD_W, LCD_H, heat_info.check_slant ? BLACK : RED);

  const uint16_t OX = 20, OY = 110;
  const uint16_t TEMP_PER_PIXEL = 1, SEC_PER_PIXEL = 1;

  // 坐标原点：20，110，x轴全长：140，y轴全长：110
  // x 轴为时间坐标，每像素 1 秒
  // y 轴为温度坐标，每像素 2 摄氏度

  // 显示坐标轴// y轴
  lcd_draw_line(20, 0, 20, 110, WHITE);    // y轴
  lcd_draw_line(0, 110, 160, 110, WHITE);  // x轴

  // 最新温度为 y 轴中值，
  // 同时限制 y 轴最大温度为 320℃，
  // 最小温度为 0℃，
  // 基准温度为 y 轴最小值

  if (record_num >= 1) {
    // 找出基准温度
    uint16_t benchmark_temp =
        temp_record[(record_num - 1) % (sizeof(temp_record) / 2)] >
                55 * TEMP_PER_PIXEL
            ? temp_record[(record_num - 1) % (sizeof(temp_record) / 2)] -
                  55 * TEMP_PER_PIXEL
            : 0;
    if (benchmark_temp > 320 - TEMP_PER_PIXEL * 110)
      benchmark_temp = 320 - TEMP_PER_PIXEL * 110;

    // 计算温度坐标
    for (size_t i = 0; i < (record_num > 140 ? 140 : record_num); i++) {
      temp_show_x[i] = 21 + i;  // range: [21, 160]
      if (temp_record[(record_num - (record_num > 140 ? 140 : record_num) + i) %
                      (sizeof(temp_record) / 2)] >
          benchmark_temp + TEMP_PER_PIXEL * 110)
        temp_show_y[i] = 0;
      else if (temp_record[(record_num - (record_num > 140 ? 140 : record_num) +
                            i) %
                           (sizeof(temp_record) / 2)] < benchmark_temp)
        temp_show_y[i] = 109;
      else
        temp_show_y[i] =
            OY - (temp_record[(record_num -
                               (record_num > 140 ? 140 : record_num) + i) %
                              (sizeof(temp_record) / 2)] -
                  benchmark_temp) /
                     TEMP_PER_PIXEL;  // range: [0, 110]
    }

    // 显示 y 轴标签
    lcd_show_num(0, 0, benchmark_temp + TEMP_PER_PIXEL * 110, 3, WHITE, WHITE,
                 12);
    lcd_show_num(0, 50, benchmark_temp + 55, 3, WHITE, WHITE, 12);
    lcd_show_num(0, 95, benchmark_temp, 3, WHITE, WHITE, 12);

    // 显示曲线
    lcd_draw_multi_line(temp_show_x, temp_show_y,
                        record_num > 140 ? 140 : record_num, WHITE);

    // 显示温度和功率
    lcd_show_font(0, 115, (uint8_t *)"温度：", WHITE, WHITE, FontSize12);
    lcd_show_num(37, 115, cur_temp, 3, WHITE, WHITE, 12);
    lcd_show_font(60, 115, (uint8_t *)"℃", WHITE, WHITE, FontSize12);

    lcd_show_font(80, 115, (uint8_t *)"功率：", WHITE, WHITE, FontSize12);
    lcd_show_num(117, 115, cur_power, 3, WHITE, WHITE, 12);
    lcd_show_str(140, 115, (uint8_t *)"W", WHITE, WHITE, 12);

  } else {
    // 显示缺省 y 轴标签
    lcd_show_num(0, 0, TEMP_PER_PIXEL * 110, 3, WHITE, WHITE, 12);
    lcd_show_num(0, 50, 55, 3, WHITE, WHITE, 12);
    lcd_show_num(0, 95, 0, 3, WHITE, WHITE, 12);

    // 显示缺省温度和功率
    lcd_show_str(0, 115, (uint8_t *)"temp: N/A C", WHITE, WHITE, 12);
    lcd_show_str(80, 115, (uint8_t *)"temp: N/A C", WHITE, WHITE, 12);
  }

  lcd_refreash_request();
}

static void btn_handler(void *param) {
  struct Button *btn = (struct Button *)param;
  PressEvent evt     = get_button_event(btn);

  switch (btn->button_id) {
    case EncoderBtn: {
      if (evt == LONG_PRESS_START) {
        set_heat_info_page_start();
        heating_stop();
      }
      break;
    }
  }
}

static void heating_task_code() {
  // 收集和显示温度和功率数据
  // 倾斜检测

  TickType_t wait_notify_tick = portMAX_DELAY, temp_record_tick = 0;

  MeasurePwrInfo_t pwr_info;
  MeasureSportInfo_t sport_info;

  int8_t target_power         = 0;
  uint8_t cur_stage_num       = 0;
  TickType_t first_reach_tick = portMAX_DELAY, cur_stage_tick = 0,
             last_check_tick = 0;

  uint8_t slant_count = 0, vl_count = 0;

  uint32_t notify_val = 0;

  while (1) {
    xTaskNotifyWait(0, 0xFFFFFFFF, &notify_val, wait_notify_tick);

    if (notify_val & (1 << 0)) {  // 启动信号
      wait_notify_tick = 0;
      cur_stage_tick   = 0;
      first_reach_tick = portMAX_DELAY;
      last_check_tick  = xTaskGetTickCount();
      record_num       = 0;
      target_power     = 0;
      cur_stage_num    = 0;
      slant_count      = 0;
      vl_count         = 0;
      heat_pad_set_max_pwr(heat_info.power_limit);
      if (heat_info.is_constant) heat_pad_set_temp(heat_info.stage[0].temp);
      continue;
    }
    if (notify_val & (1 << 1)) {  // 停止信号
      wait_notify_tick = portMAX_DELAY;

      heat_pad_disable();
      continue;
    }

    measure_pwr_data_get(&pwr_info);
    measure_sport_data_get(&sport_info);

    // 检测倾斜状态和电压
    if (heat_info.check_slant) {
      if (sport_info.acc_mg_all < 800 || sport_info.acc_mg_all > 1200 ||
          sport_info.acc_z_mg < 900 || sport_info.acc_z_mg > 1100)
        slant_count++;
      else
        slant_count = 0;
      if (pwr_info.pwr_in_vol < 16.5)
        vl_count++;
      else
        vl_count = 0;
      if (slant_count >= 5U) {
        log_i(
            "stop heat, reason: machine tilt, acc all: %.2f mg, acc "
            "z: %.2f mg",
            sport_info.acc_mg_all, sport_info.acc_z_mg);
        heating_stop();
        remind_page_start(RemindTypeSlant);
        continue;
      } else if (vl_count >= 20U) {
        log_i("stop heat, reason: voltage too low, voltage: %.2f",
              pwr_info.pwr_in_vol);
        heating_stop();
        remind_page_start(RemindTypeVl);
        continue;
      }
    }

    // 控制温度
    if (!heat_info.is_constant) {
      // 计算加热时间
      // 正负误差 5 摄氏度都算达到温度区间
      if (fabsf(pwr_info.heat_pad_temp - heat_info.stage[cur_stage_num].temp) <
          5.0f) {
        cur_stage_tick += xTaskGetTickCount() - last_check_tick;
        if (first_reach_tick == portMAX_DELAY) {
          first_reach_tick = xTaskGetTickCount();
          log_i("first reach stage %u temp, tick val: %u, be equal to %u ms",
                cur_stage_num, first_reach_tick,
                first_reach_tick / portTICK_PERIOD_MS);
        }
      }
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

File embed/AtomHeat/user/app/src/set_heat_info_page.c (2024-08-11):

#include "set_heat_info_page.h"
/***/
#include "color.h"
#include "encoder.h"
#include "lcd_init.h"
#include "heating.h"
#include "my_lcd.h"
#include "heat_info.h"
#include "measure.h"
#include "buzzer.h"
#include "multi_button_port.h"
/***/
#define LOG_TAG "set page"
#include "elog.h"
//
#include "multi_button.h"
#include "easyflash.h"
//
#include "FreeRTOS.h"
#include "queue.h"
#include "task.h"
#include "event_groups.h"
/***/
#include <stdint.h>
#include <stdio.h>
#include <stdlib.h>

/*
 * 设置加热流程界面
 * 此界面可设置加热流程、功率限制
 * 分段加热分为预热段、加热段、焊接端、保温段和冷却段五段
 * 长按按键可保存预设、短按按键可加载预设
 */

// static EventGroupHandle_t set_page_evtgp_handle;
// static StaticEventGroup_t set_page_evtgp;

static HeatInfo_t heat_info;

static uint8_t menu_num = 0;
static uint8_t select   = 0;

static struct Button btn1;
static struct Button btn2;
static struct Button btn3;
static struct Button btn4;
static struct Button btn5;
static struct Button encoder_btn;

// 从加热界面退出会在加热界面，用这个定时器刷新一下
static TaskHandle_t refreash_task_handle;
static StaticTask_t refreash_task;
static uint8_t refreash_task_stack[1024];

static TimerHandle_t auto_close_screen_timer_handle;
static StaticTimer_t auto_close_screen_timer;

static void set_heat_procedure_page_pause();
static void set_heat_procedure_page_resume();

const static uint16_t constant_select_indicator_pos_cn[4][2] = {
    {68, 0},
    {140, 0},   //
    {100, 14},  //
    {85, 27},   //
};

const static uint16_t stage_select_indicator_pos_cn[13][2] = {
    {68, 0},   {140, 0},    //
    {100, 14},              //
    {86, 51},  {134, 51},   //
    {86, 67},  {134, 67},   //
    {86, 83},  {134, 83},   //
    {86, 99},  {134, 99},   //
    {86, 115}, {134, 115},  //
};

const static uint16_t constant_select_indicator_pos_en[4][2] = {
    {70, 3},
    {135, 3},   //
    {100, 14},  //
    {85, 27},   //
};

const static uint16_t stage_select_indicator_pos_en[13][2] = {
    {70, 3},   {135, 3},    //
    {100, 19},              //
    {80, 51},  {135, 51},   //
    {80, 67},  {135, 67},   //
    {80, 83},  {135, 83},   //
    {80, 99},  {135, 99},   //
    {80, 115}, {135, 115},  //
};

static void set_page_ui_renew_cn() {
  lcd_fill(0, 0, LCD_W, LCD_H, heat_info.check_slant ? BLACK : RED);

  lcd_show_font(
      0, 0,
      heat_info.is_constant ? (uint8_t *)"模式：恒温" : (uint8_t *)"模式：分段",
      WHITE, WHITE, FontSize12);

  lcd_show_font(
      84, 0, heat_info.check_slant ? (uint8_t *)"开始" : (uint8_t *)"强制开始",
      WHITE, WHITE, FontSize12);

  lcd_show_font(0, 14, (uint8_t *)"功率限制：", WHITE, WHITE, FontSize12);
  lcd_show_num(61, 14, heat_info.power_limit, 3, WHITE, WHITE, 12);
  lcd_show_str(80, 14, (uint8_t *)"W", WHITE, WHITE, 12);
  if (heat_info.is_constant) {
    lcd_show_font(0, 27, (uint8_t *)"温度：", WHITE, WHITE, FontSize12);
    lcd_show_num(37, 27, heat_info.stage[0].temp, 3, WHITE, WHITE, 12);
    lcd_show_font(58, 27, (uint8_t *)"℃", WHITE, WHITE, FontSize12);
  } else {
    const uint16_t TEMP_POS_X = 50, DURATION_S_POS_X = 95;

    lcd_show_font(TEMP_POS_X, 35, (uint8_t *)"温度", WHITE, WHITE, FontSize12);
    lcd_show_font(DURATION_S_POS_X, 35, (uint8_t *)"时间", WHITE, WHITE,
                  FontSize12);

    lcd_show_font(0, 51, (uint8_t *)"预热段", WHITE, WHITE, FontSize12);
    lcd_show_num(TEMP_POS_X, 51, heat_info.stage[0].temp, 3, WHITE, WHITE, 12);
    lcd_show_font(TEMP_POS_X + 20, 51, (uint8_t *)"℃", WHITE, WHITE,
                  FontSize12);
    lcd_show_num(DURATION_S_POS_X, 51, heat_info.stage[0].duartion_s, 4, WHITE,
                 WHITE, 12);
    lcd_show_str(DURATION_S_POS_X + 25, 51, (uint8_t *)"s", WHITE, WHITE, 12);

    lcd_show_font(0, 67, (uint8_t *)"加热段", WHITE, WHITE, FontSize12);
    lcd_show_num(TEMP_POS_X, 67, heat_info.stage[1].temp, 3, WHITE, WHITE, 12);
    lcd_show_font(TEMP_POS_X + 20, 67, (uint8_t *)"℃", WHITE, WHITE,
                  FontSize12);
    lcd_show_num(DURATION_S_POS_X, 67, heat_info.stage[1].duartion_s, 4, WHITE,
                 WHITE, 12);
    lcd_show_str(DURATION_S_POS_X + 25, 67, (uint8_t *)"s", WHITE, WHITE, 12);

    lcd_show_font(0, 83, (uint8_t *)"焊接段", WHITE, WHITE, FontSize12);
    lcd_show_num(TEMP_POS_X, 83, heat_info.stage[2].temp, 3, WHITE, WHITE, 12);
    lcd_show_font(TEMP_POS_X + 20, 83, (uint8_t *)"℃", WHITE, WHITE,
                  FontSize12);
    lcd_show_num(DURATION_S_POS_X, 83, heat_info.stage[2].duartion_s, 4, WHITE,
                 WHITE, 12);
    lcd_show_str(DURATION_S_POS_X + 25, 83, (uint8_t *)"s", WHITE, WHITE, 12);

    lcd_show_font(0, 99, (uint8_t *)"保温段", WHITE, WHITE, FontSize12);
    lcd_show_num(TEMP_POS_X, 99, heat_info.stage[3].temp, 3, WHITE, WHITE, 12);
    lcd_show_font(TEMP_POS_X + 20, 99, (uint8_t *)"℃", WHITE, WHITE,
                  FontSize12);
    lcd_show_num(DURATION_S_POS_X, 99, heat_info.stage[3].duartion_s, 4, WHITE,
                 WHITE, 12);
    lcd_show_str(DURATION_S_POS_X + 25, 99, (uint8_t *)"s", WHITE, WHITE, 12);

    lcd_show_font(0, 115, (uint8_t *)"冷却段", WHITE, WHITE, FontSize12);
    lcd_show_num(TEMP_POS_X, 115, heat_info.stage[4].temp, 3, WHITE, WHITE, 12);
    lcd_show_font(TEMP_POS_X + 20, 115, (uint8_t *)"℃", WHITE, WHITE,
                  FontSize12);
    lcd_show_num(DURATION_S_POS_X, 115, heat_info.stage[4].duartion_s, 4, WHITE,
                 WHITE, 12);
    lcd_show_str(DURATION_S_POS_X + 25, 115, (uint8_t *)"s", WHITE, WHITE, 12);
  }
  // 显示光标
  lcd_show_str(
      heat_info.is_constant ? constant_select_indicator_pos_cn[menu_num][0]
                            : stage_select_indicator_pos_cn[menu_num][0],
      heat_info.is_constant ? constant_select_indicator_pos_cn[menu_num][1]
                            : stage_select_indicator_pos_cn[menu_num][1],
      (uint8_t *)(select ? "<<" : "< "), WHITE, WHITE, 12);

  lcd_refreash_request();
}
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

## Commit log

2024-08-11 第一次提交
    [BOM_addition.xlsx, other.xlsx, 加热平面.STEP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]
2024-08-13 修改 readme 、BOM
    [BOM_Board1_V0.3_Schematic1_V0.3_2024-08-13.xlsx, BOM_Board2_V0.2_Schematic2_V0.2_2024-08-13.xlsx, other.xlsx]
